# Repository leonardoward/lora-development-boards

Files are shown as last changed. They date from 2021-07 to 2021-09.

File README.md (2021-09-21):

# RFM95W-915S2 Development Board #

<p align="center">
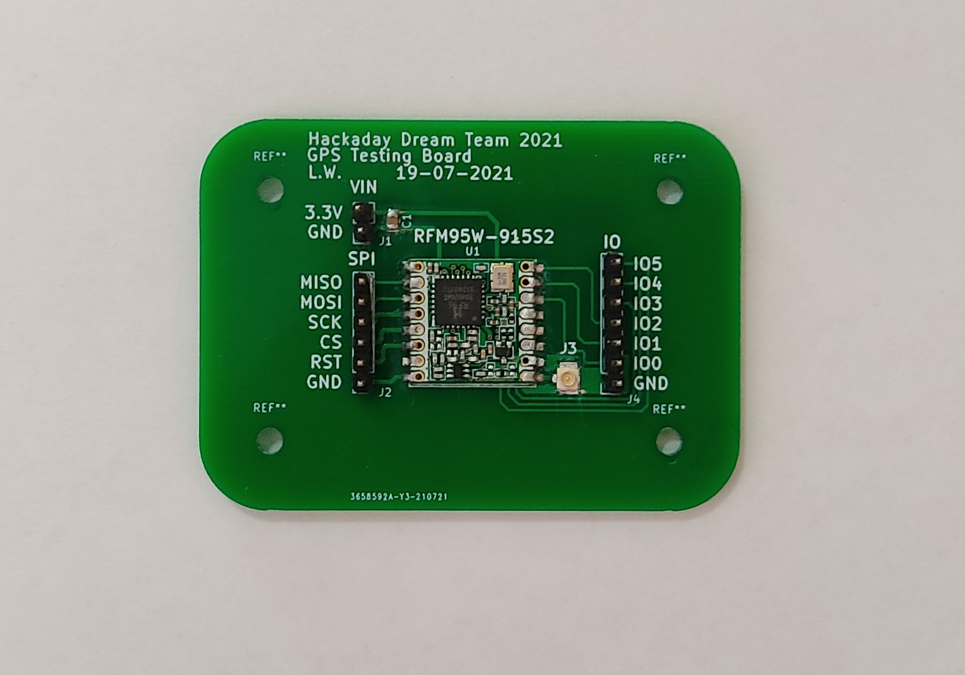
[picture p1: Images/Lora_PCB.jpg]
  
</p>

This repository contains the design of a development board for the RFM95W-915S2. The PCB was designed using KiCad.

The [RFM95W-915S2 Development board](https://hackaday.io/project/173457/log/196116-lora-rfm95w-915s2-development-board) is a PCB that contains a RFM95W LoRa transceiver, a [U.FL connector](https://www.digikey.com/en/products/detail/hirose-electric-co-ltd/U-FL-R-SMT-1-10/2391570) for the external antenna, a decoupling capacitor and a group of headers connected to the different pins of the transceiver. The transceiver can be used as a sender or a receiver.

## Table of Contents

1. [Schematic](#schematic)
2. [Bill of Materials](#bill-of-materials)
3. [3D Model](#3d-model)
4. [Firmware and Testing](#firmware-and-testing)
5. [Authors](#authors)

## Schematic ##

<p align="center">
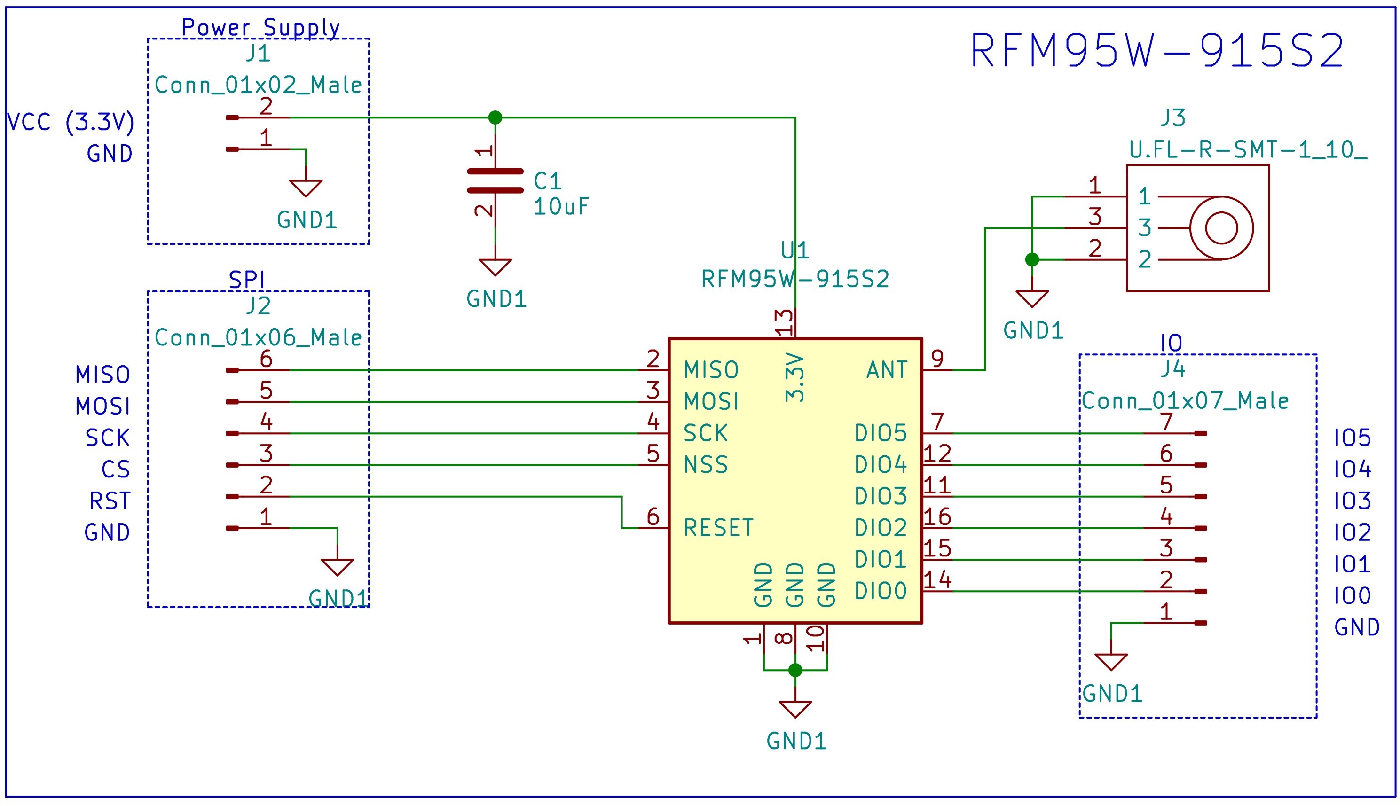
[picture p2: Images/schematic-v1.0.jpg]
  
</p>

**[Back to top](#table-of-contents)**

## Bill of Materials ##

| Reference | Quantity |
| --- | --- |
| [RFM95W-915S2 LoRa™ Transceiver Module 915MHz SMD](https://www.digikey.com/en/products/detail/rf-solutions/RFM95W-915S2/6564923)  | 1 |
| [10 µF ±10% 6.3V Ceramic Capacitor 0805](https://www.digikey.com/en/products/detail/samsung-electro-mechanics/CL21A106KQCLNNC/3888062)  | 1 |
| [U.FL (UMCC) Connector Receptacle, Male Pin 50 Ohm SMD](https://www.digikey.com/en/products/detail/hirose-electric-co-ltd/U-FL-R-SMT-1-10/2391570) | 1 |
| [Conn Header 40POS 2.54](https://www.digikey.com/en/products/detail/3m/2340-6111TG/1237275) | 1 |

**[Back to top](#table-of-contents)**

## 3D Model ##

<p align="center">
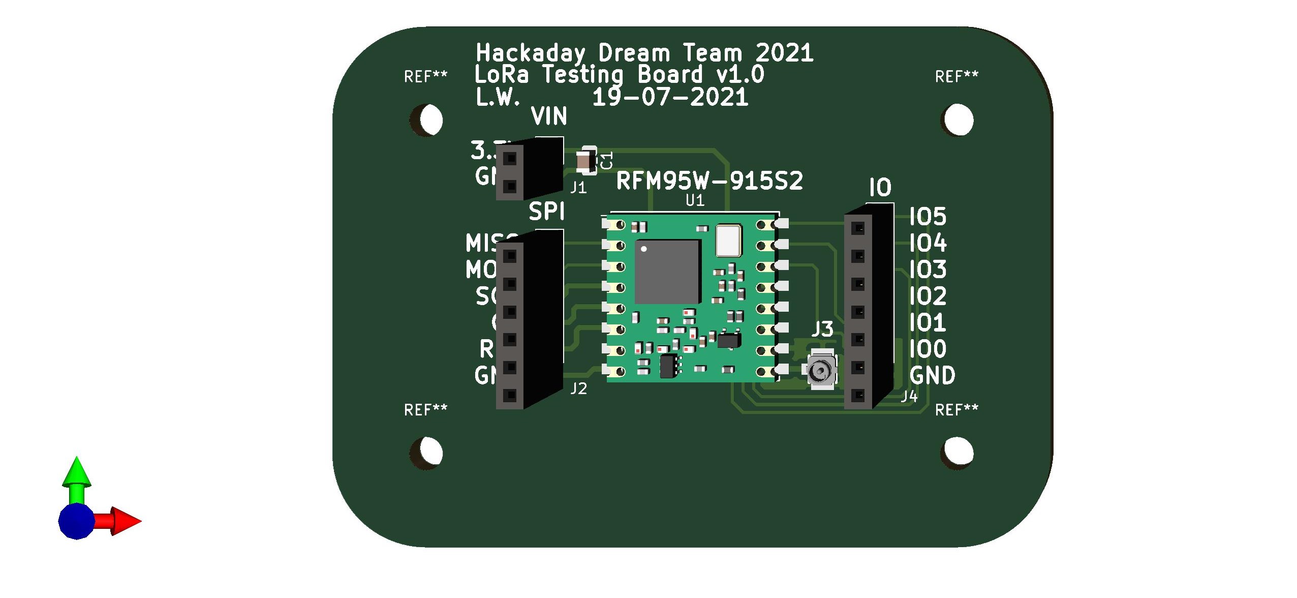
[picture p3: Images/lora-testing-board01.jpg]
  
</p>

<p align="center">
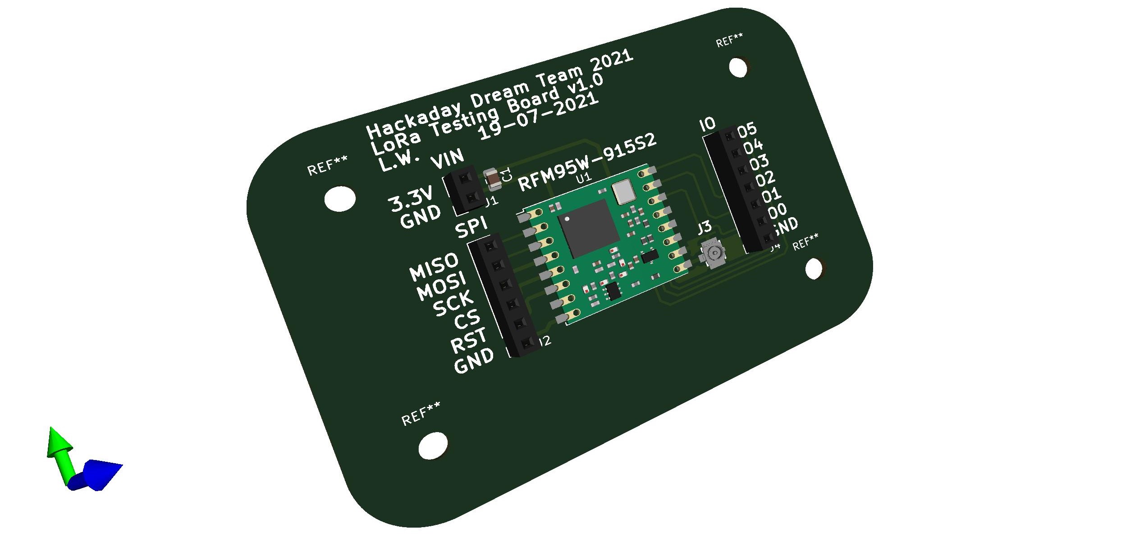
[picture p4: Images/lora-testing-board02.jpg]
  
</p>

**[Back to top](#table-of-contents)**

## Firmware and Testing ##

The webpage randomnerdtutorials.com has an amazing tutorial named [ESP32 with LoRa using Arduino IDE – Getting Started](https://randomnerdtutorials.com/esp32-lora-rfm95-transceiver-arduino-ide/), that tutorial contains detailed information about how to use the RFM95 with an ESP32 (the same microcontroller that was selected for our designs). I used the same firmware and connections provided by the tutorial.

The test requires 2 transceivers, one of them will be used as a sender and the other as a receiver. In this case, one of the transceivers is the  RFM95W-915S2 Development board and the other one is the [RFM95W transceiver from Adafruit](https://www.digikey.com/en/products/detail/adafruit-industries-llc/3072/6005357).

The connections are the following:

| ESP32 | RFM95W-915S2 Development Board |
| --- | --- |
| 3V3  | 3.3V |
| GND  | GND |
| GPIO 14  | RST |
| GPIO 5  | CS |
| GPIO 18  | SCK |
| GPIO 23  | MOSI |
| GPIO 19  | 	MISO |

<p align="center">
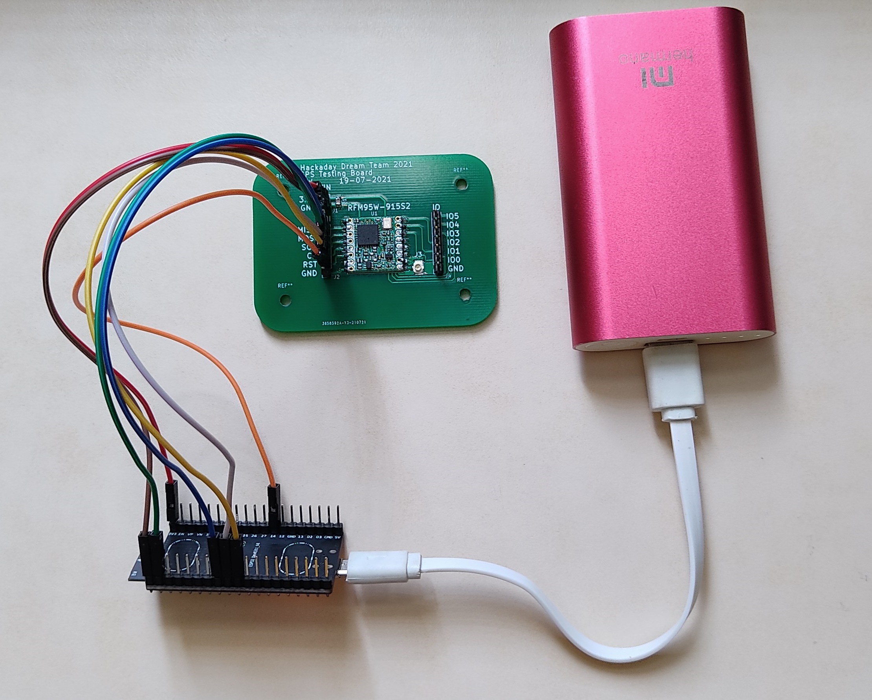
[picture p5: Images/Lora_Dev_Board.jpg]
  
</p>

| ESP32 | RFM95W Board from Adafruit |
| --- | --- |
| 3V3  | VIN |
| GND  | GND |
| GPIO 14  | RST |
| GPIO 5  | CS |
| GPIO 18  | SCK |
| GPIO 23  | MOSI |
| GPIO 19  | 	MISO |

<p align="center">
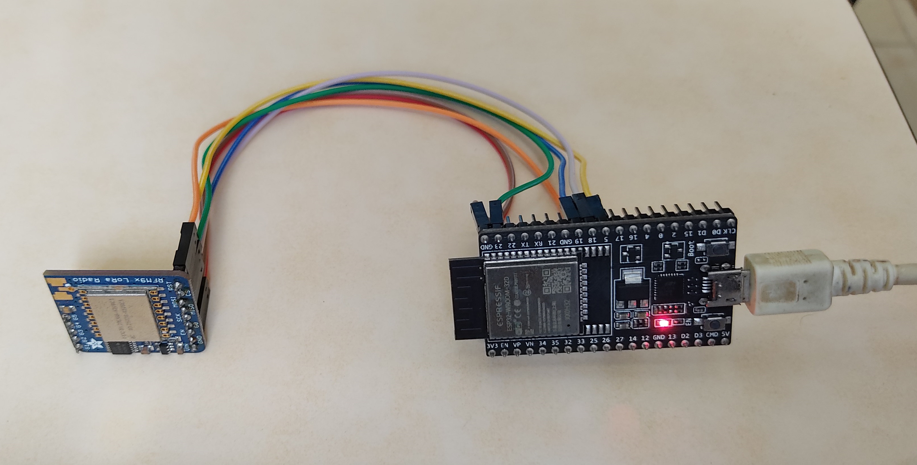
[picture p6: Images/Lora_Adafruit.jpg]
  
</p>

This repository contains a folder named /Firmware/ that contains the project for the transceiver as a [receiver](https://github.com/leonardoward/lora-development-boards/blob/main/Firmware/esp32_RFM95_receiver/esp32_RFM95_receiver.ino) and a [sender](https://github.com/leonardoward/lora-development-boards/blob/main/Firmware/esp32_RFM95_sender/esp32_RFM95_sender.ino).  

Both of the RFM95W Boards were used as a sender and receiver, the result was successful in both cases. During the test, one of the transceivers sends the package "hello counter", where the counter is a number that goes from 0 to 32767. The other transceiver receives the package and prints the message through serial.

### Requisites ###

1. [ESP32 Add-on in Arduino IDE](https://randomnerdtutorials.com/installing-the-esp32-board-in-arduino-ide-windows-instructions/)
2. [LoRa Library](https://randomnerdtutorials.com/esp32-lora-rfm95-transceiver-arduino-ide/)

Results visualized in the serial monitor from the receiver circuit:

<p align="center">
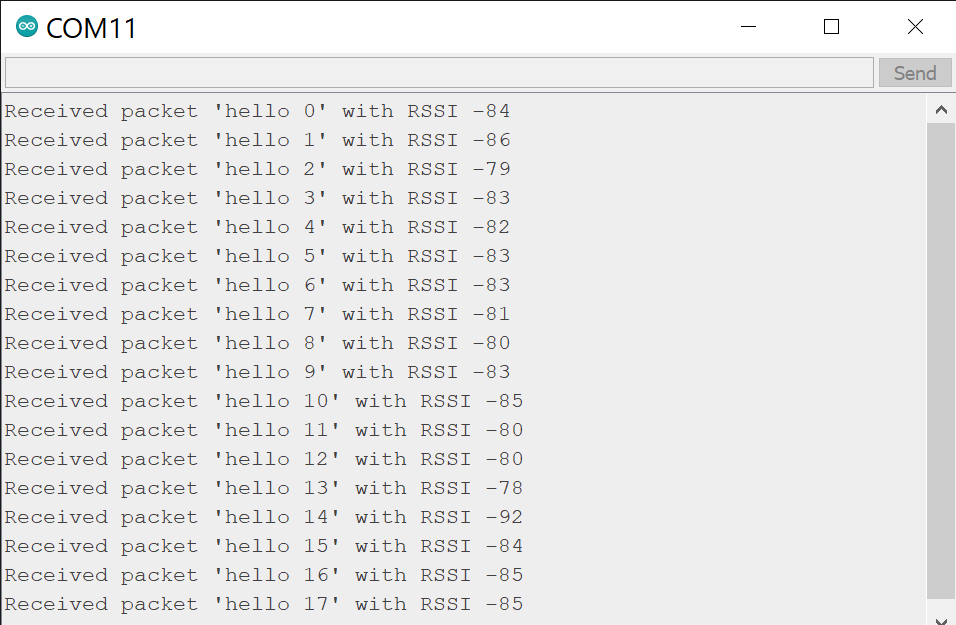
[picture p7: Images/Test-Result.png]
  
</p>

For more information about the firmware visit the [original tutorial for the RFM95W](https://randomnerdtutorials.com/esp32-lora-rfm95-transceiver-arduino-ide/).

**[Back to top](#table-of-contents)**

## Authors ##

* **[Leonardo Ward](https://github.com/leonardoward)**

**[Back to top](#table-of-contents)**

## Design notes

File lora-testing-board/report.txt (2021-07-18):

Info: Checking netlist symbol footprint "C1:/60F514A5:Capacitor_SMD:C_0805_2012Metric".
Info: Checking netlist symbol footprint "J1:/60F44B42:Connector_PinSocket_2.54mm:PinSocket_1x02_P2.54mm_Vertical".
Info: Checking netlist symbol footprint "J2:/60F3E586:Connector_PinSocket_2.54mm:PinSocket_1x06_P2.54mm_Vertical".
Info: Checking netlist symbol footprint "J3:/60F52CF6:U.FL-R-SMT-1(10):U.FL-R-SMT-1_10_".
Info: Checking netlist symbol footprint "J4:/60F51643:Connector_PinSocket_2.54mm:PinSocket_1x07_P2.54mm_Vertical".
Info: Checking netlist symbol footprint "U1:/60F3A12A:RF_Module:HOPERF_RFM9XW_SMD".
Adding new symbol C1 footprint Capacitor_SMD:C_0805_2012Metric.
Adding new symbol J1 footprint Connector_PinSocket_2.54mm:PinSocket_1x02_P2.54mm_Vertical.
Adding new symbol J2 footprint Connector_PinSocket_2.54mm:PinSocket_1x06_P2.54mm_Vertical.
Adding new symbol J3 footprint U.FL-R-SMT-1(10):U.FL-R-SMT-1_10_.
Adding new symbol J4 footprint Connector_PinSocket_2.54mm:PinSocket_1x07_P2.54mm_Vertical.
Adding new symbol U1 footprint RF_Module:HOPERF_RFM9XW_SMD.

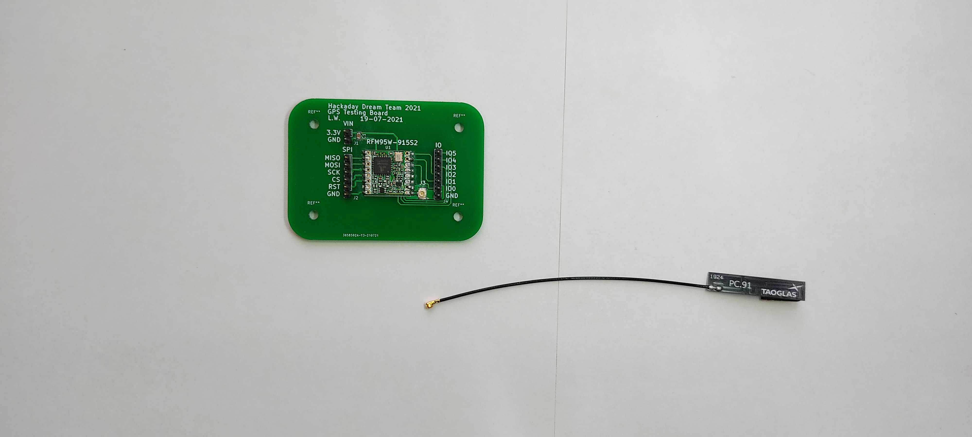
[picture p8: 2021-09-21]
Images/Lora_antena01.jpg

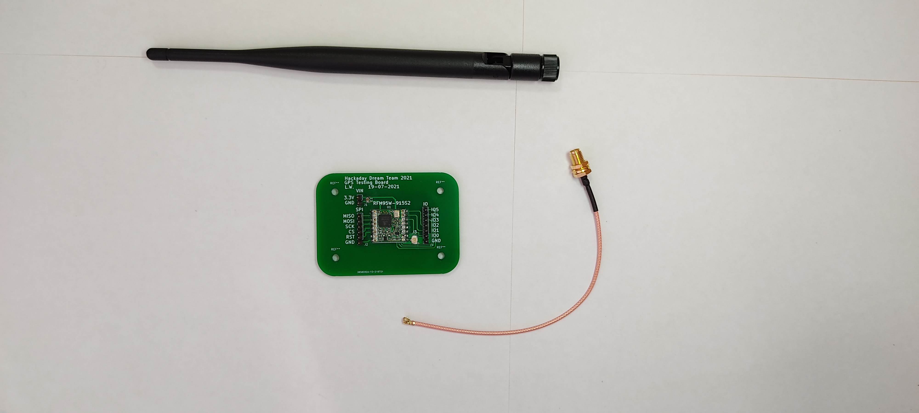
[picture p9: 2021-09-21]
Images/Lora_antena02.jpg

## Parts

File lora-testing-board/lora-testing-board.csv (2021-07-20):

Source: | C:\Ext\lora-development-boards\lora-testing-board\lora-testing-board.sch
Date: | 7/19/2021 5:52:30 PM
Tool: | Eeschema (5.1.10)-1
Generator: | C:\Program Files\KiCad\bin\scripting\plugins/bom_csv_grouped_by_value.py
Component Count: | 6
Individual Components:
Item | Qty | Reference(s) | Value | LibPart | Footprint | Datasheet | Description | Manufacturer | Manufacturer Name | Manufacturer Part Number | Supplier 1 | Supplier 2 | Supplier Part Number 1 | Supplier Part Number 2
 |  | C1 | C-10uF-0805 | C-10uF-0805:C-10uF-0805 | Capacitor_SMD:C_0805_2012Metric |  |  | Samsung Electro-Mechanics |  | CL21A106KQCLNNC | Digi-Key |  | 1276-2404-1-ND
 |  | J1 | Conn_01x02_Male | Connector:Conn_01x02_Male | Connector_PinSocket_2.54mm:PinSocket_1x02_P2.54mm_Vertical | ~
 |  | J2 | Conn_01x06_Male | Connector:Conn_01x06_Male | Connector_PinSocket_2.54mm:PinSocket_1x06_P2.54mm_Vertical | ~
 |  | J3 | U.FL-R-SMT-1_10_ | U.FL-R-SMT-1_10_:U.FL-R-SMT-1_10_ | U.FL-R-SMT-1(10):U.FL-R-SMT-1_10_ | https://www.hirose.com/product/document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 | UFL SMT PCB receptable,DC-6GHz Hirose Straight 50 Surface Mount UFL Connector, Receptacle, Solder Termination Coaxial |  | Hirose | U.FL-R-SMT-1(10) | Digi-Key | Mouser | H11891CT-ND | 798-U.FL-R-SMT-110
 |  | J4 | Conn_01x07_Male | Connector:Conn_01x07_Male | Connector_PinSocket_2.54mm:PinSocket_1x07_P2.54mm_Vertical | ~
 |  | U1 | RFM95W-915S2 | RFM95W-915S2:RFM95W-915S2 | RF_Module:HOPERF_RFM9XW_SMD | https://www.rfsolutions.co.uk/downloads/1463993415RFM95_96_97_98W.pdf |  |  |  |  | Digi-Key |  | RFM95W-915S2-ND
Collated Components:
Item | Qty | Reference(s) | Value | LibPart | Footprint | Datasheet | Description | Manufacturer | Manufacturer Name | Manufacturer Part Number | Supplier 1 | Supplier 2 | Supplier Part Number 1 | Supplier Part Number 2
1 | 1 | C1 | C-10uF-0805 | C-10uF-0805:C-10uF-0805 | Capacitor_SMD:C_0805_2012Metric |  |  | Samsung Electro-Mechanics |  | CL21A106KQCLNNC | Digi-Key |  | 1276-2404-1-ND
2 | 1 | J1 | Conn_01x02_Male | Connector:Conn_01x02_Male | Connector_PinSocket_2.54mm:PinSocket_1x02_P2.54mm_Vertical | ~
3 | 1 | J2 | Conn_01x06_Male | Connector:Conn_01x06_Male | Connector_PinSocket_2.54mm:PinSocket_1x06_P2.54mm_Vertical | ~
4 | 1 | J3 | U.FL-R-SMT-1_10_ | U.FL-R-SMT-1_10_:U.FL-R-SMT-1_10_ | U.FL-R-SMT-1(10):U.FL-R-SMT-1_10_ | https://www.hirose.com/product/document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 | UFL SMT PCB receptable,DC-6GHz Hirose Straight 50 Surface Mount UFL Connector, Receptacle, Solder Termination Coaxial |  | Hirose | U.FL-R-SMT-1(10) | Digi-Key | Mouser | H11891CT-ND | 798-U.FL-R-SMT-110
5 | 1 | J4 | Conn_01x07_Male | Connector:Conn_01x07_Male | Connector_PinSocket_2.54mm:PinSocket_1x07_P2.54mm_Vertical | ~
6 | 1 | U1 | RFM95W-915S2 | RFM95W-915S2:RFM95W-915S2 | RF_Module:HOPERF_RFM9XW_SMD | https://www.rfsolutions.co.uk/downloads/1463993415RFM95_96_97_98W.pdf |  |  |  |  | Digi-Key |  | RFM95W-915S2-ND

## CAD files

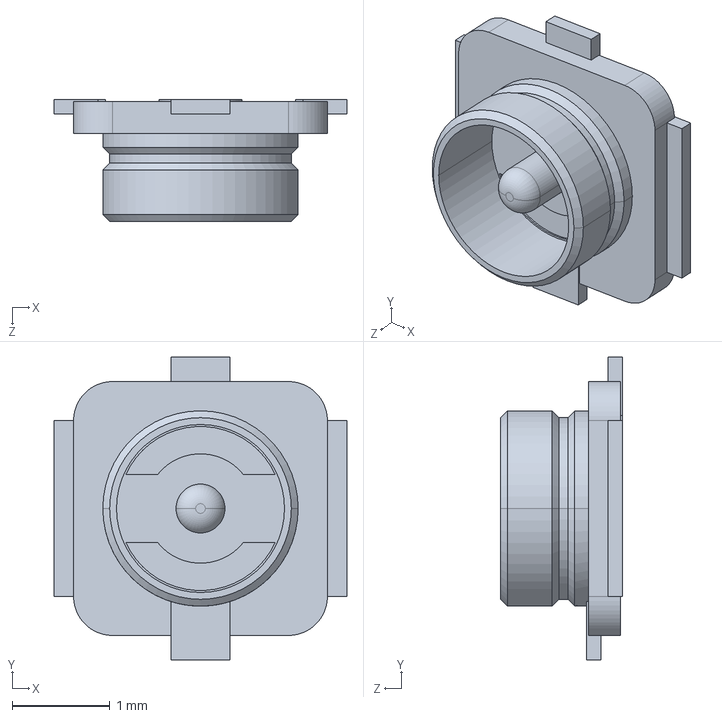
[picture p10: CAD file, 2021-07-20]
lora-testing-board/3D/U.FL-R-SMT-1_10_.stp
3.00 x 3.10 x 1.25 mm

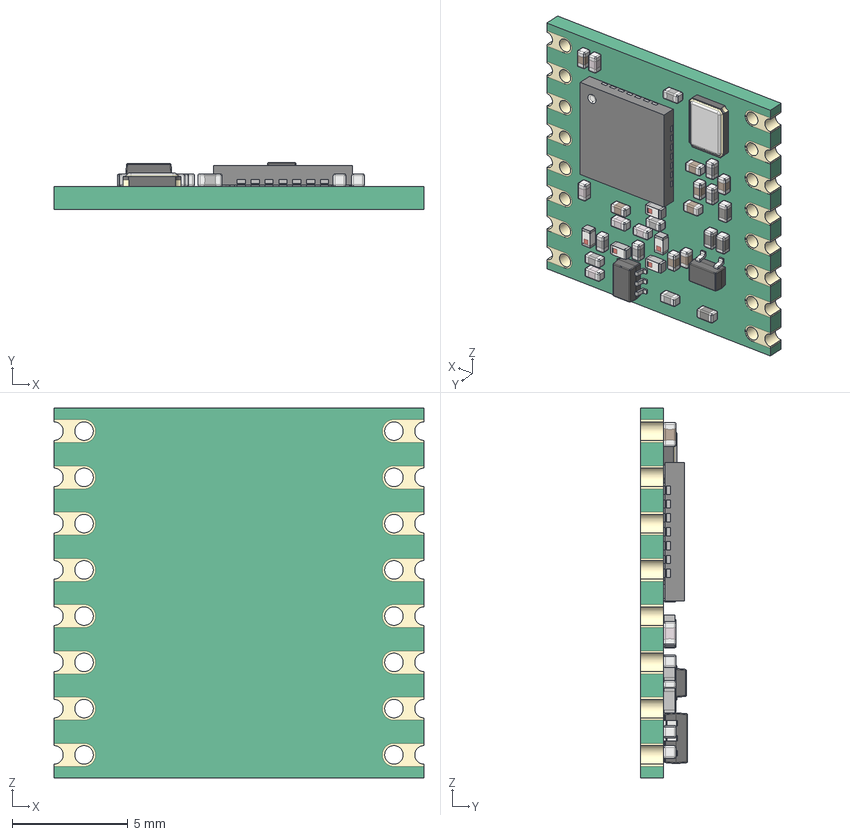
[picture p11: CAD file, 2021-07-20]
lora-testing-board/3D/RFM95 LoRa v15.step
16.0 x 2.04 x 16.0 mm
QFN 28
SMD Crystal
CAP 0403 x 8
CAP Ceramic 0403 x 8
Res 0403 x 4
CAP ML 0403 x 5
SOT-323
Inductor SMD 0403 x 5
SOT-363

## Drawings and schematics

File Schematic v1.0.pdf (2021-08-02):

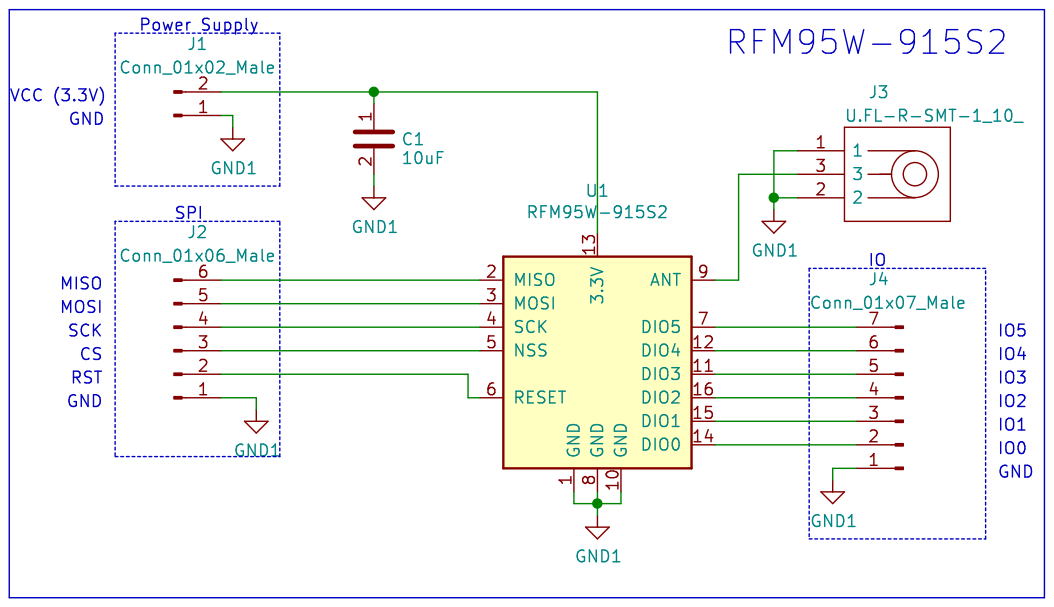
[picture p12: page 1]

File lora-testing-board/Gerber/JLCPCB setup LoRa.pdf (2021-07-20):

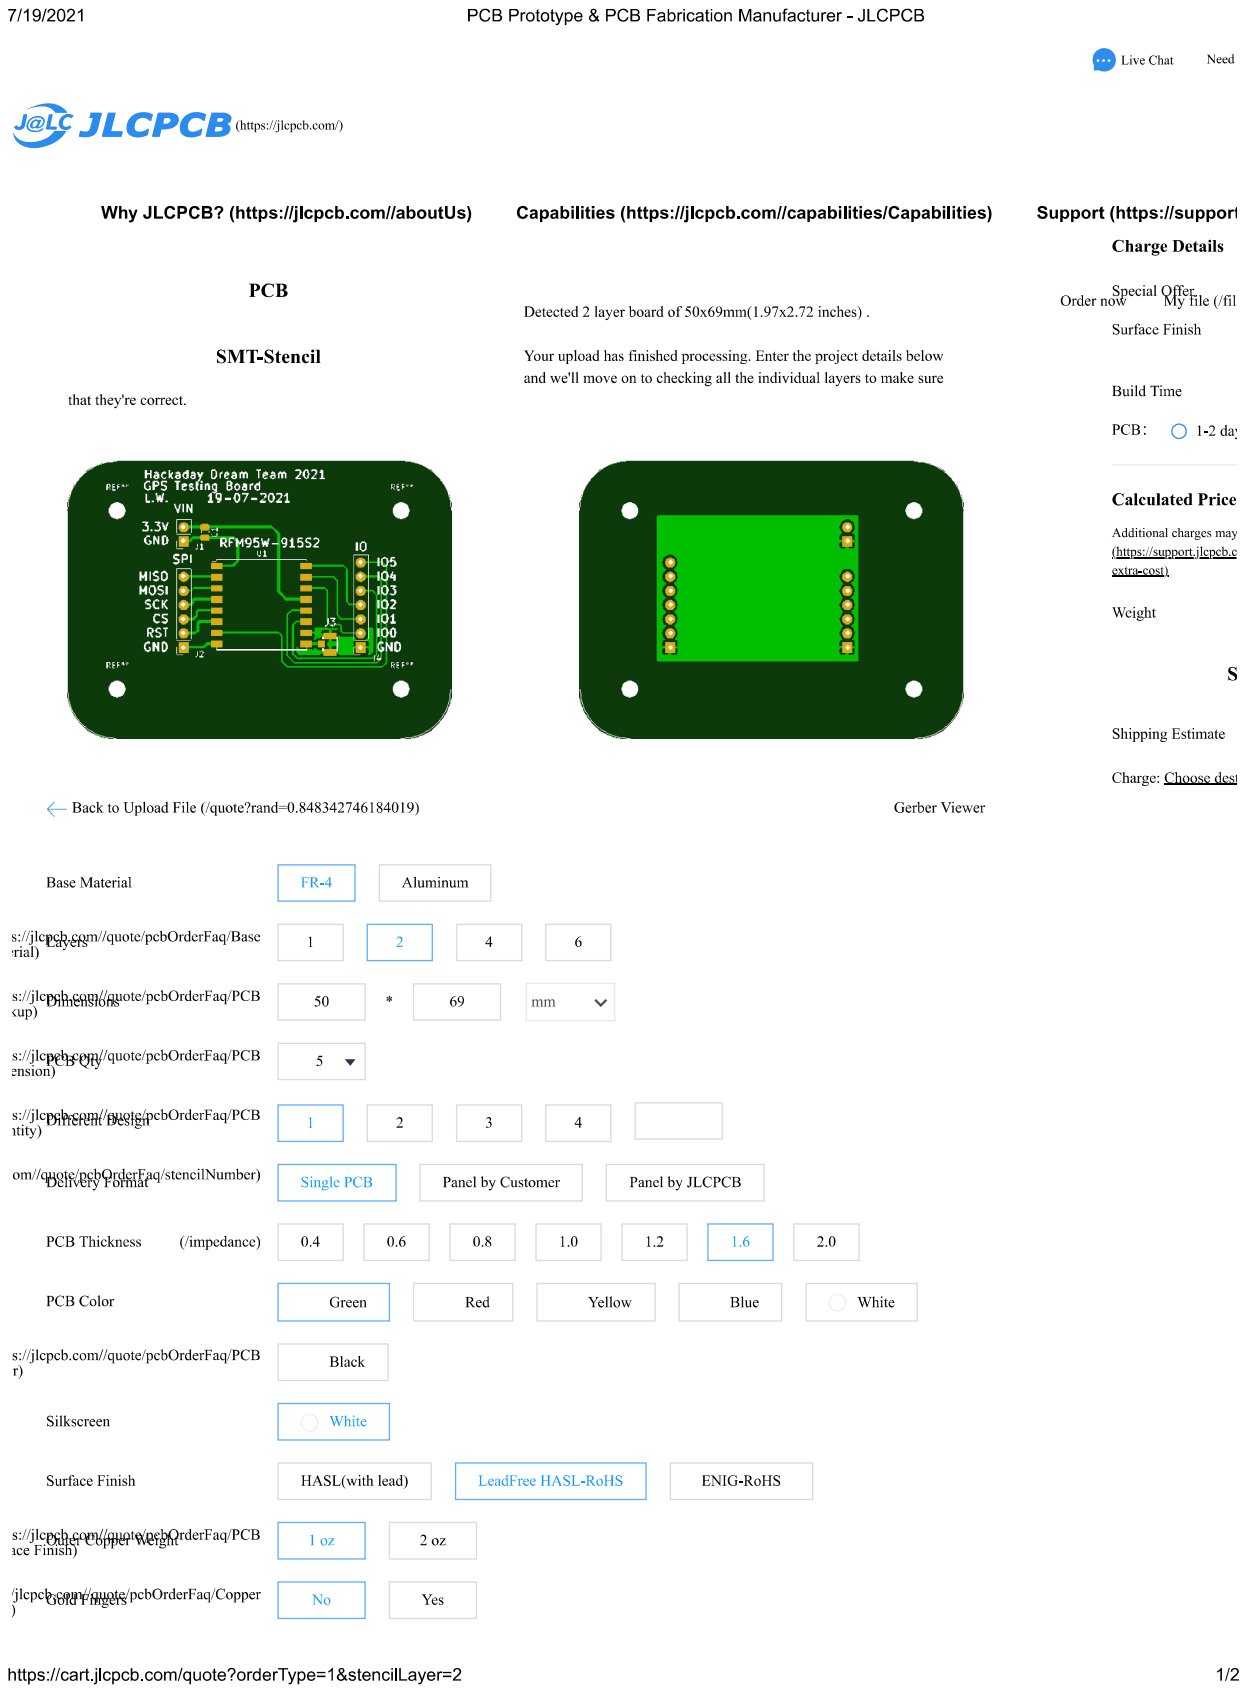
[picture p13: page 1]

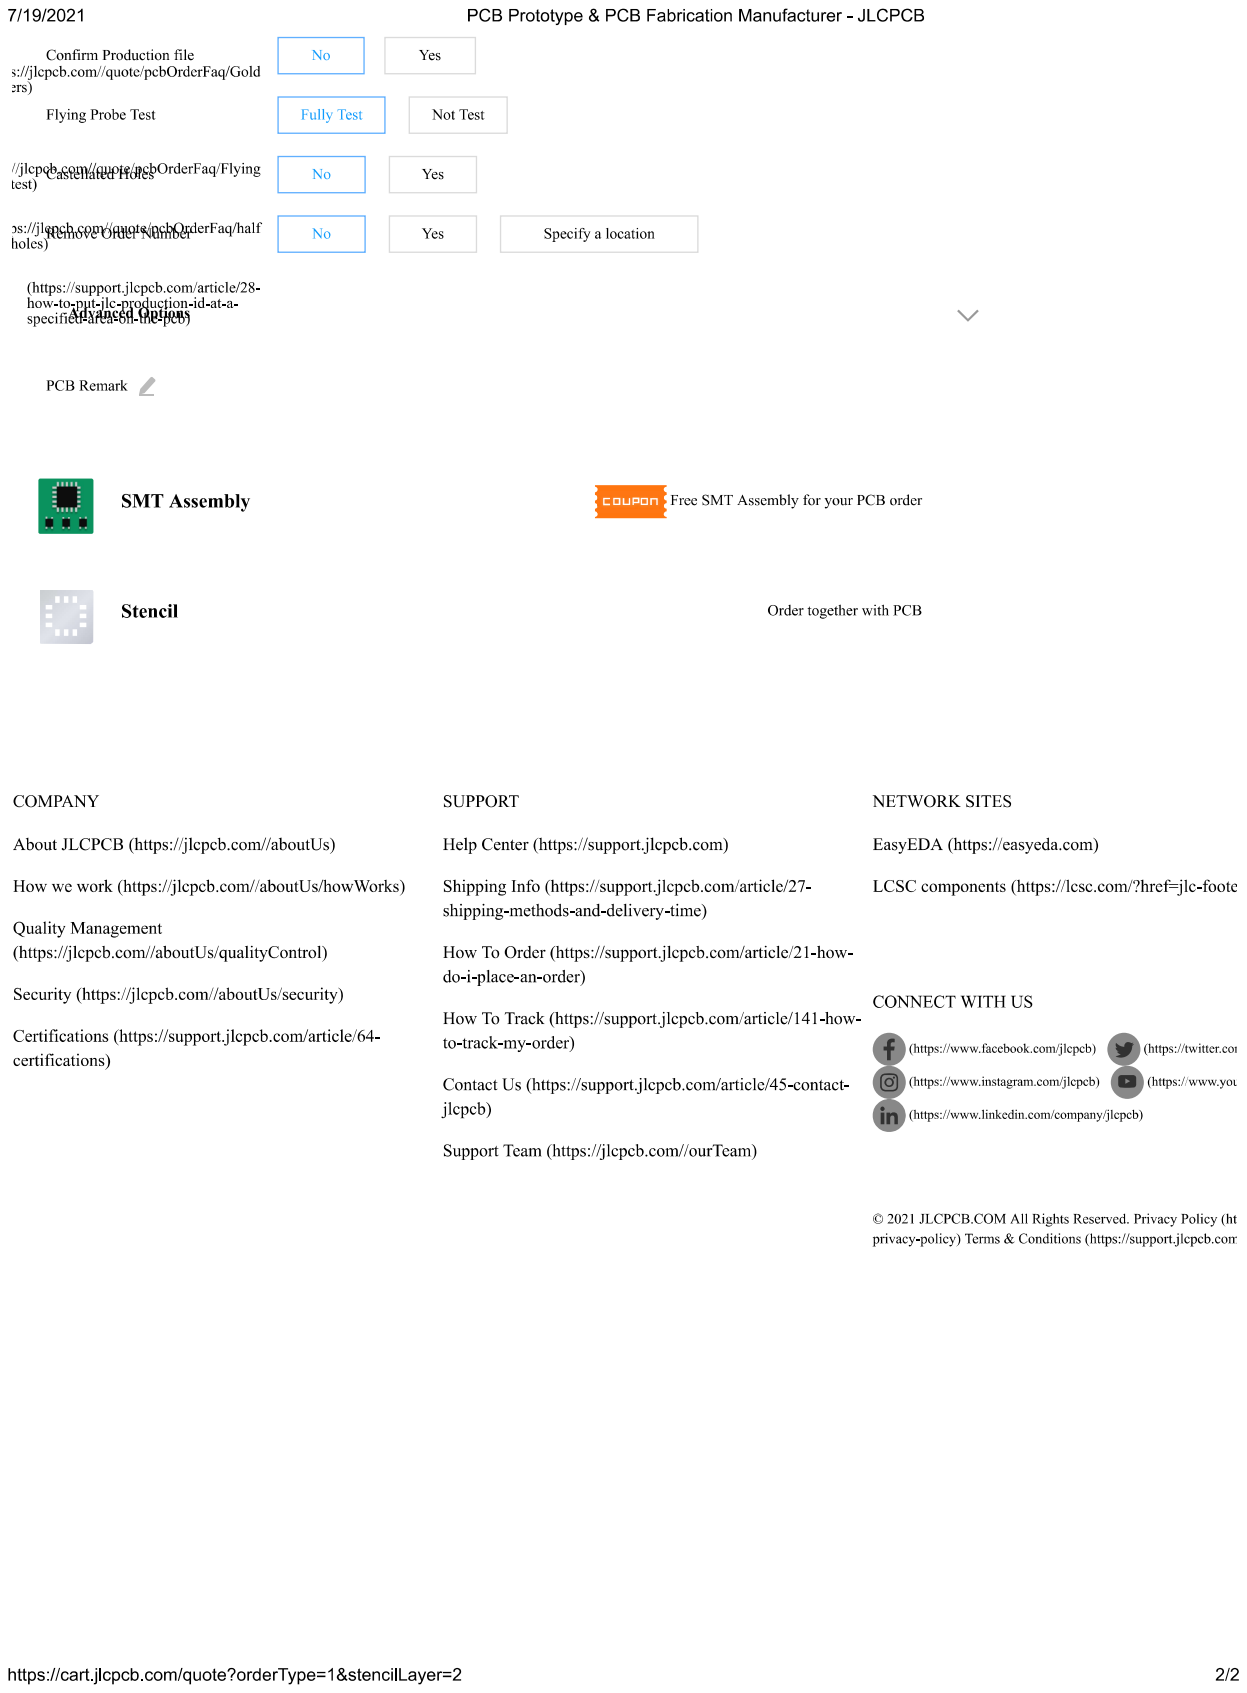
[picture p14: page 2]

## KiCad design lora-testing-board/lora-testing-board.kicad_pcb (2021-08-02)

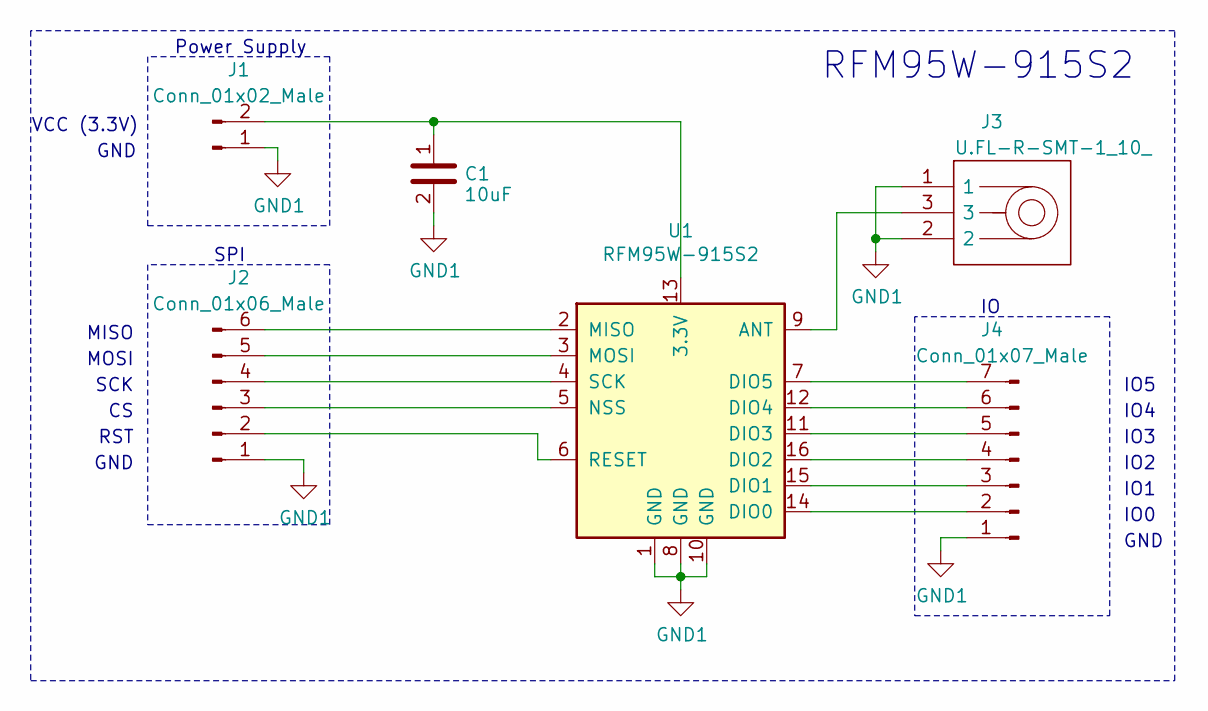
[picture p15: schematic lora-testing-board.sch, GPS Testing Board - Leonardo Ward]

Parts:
C1: 10uF; C_0805_2012Metric; Manufacturer Part Number CL21A106KQCLNNC
J1: Conn_01x02_Male; PinSocket_1x02_P2.54mm_Vertical
J2: Conn_01x06_Male; PinSocket_1x06_P2.54mm_Vertical
J3: U.FL-R-SMT-1_10_; Manufacturer Part Number U.FL-R-SMT-1(10)
J4: Conn_01x07_Male; PinSocket_1x07_P2.54mm_Vertical
U1: RFM95W-915S2; HOPERF_RFM9XW_SMD

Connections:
GND1: C1.2, J1.1, J2.1, J3.1, J3.2, J4.1, U1.1 (GND), U1.8 (GND), U1.10 (GND)
unnamed: C1.1, J1.2, U1.13 (3.3V)
unnamed: J2.2, U1.6 (RESET)
unnamed: J2.3, U1.5 (NSS)
unnamed: J2.4, U1.4 (SCK)
unnamed: J2.5, U1.3 (MOSI)
unnamed: J2.6, U1.2 (MISO)
unnamed: J3.3, U1.9 (ANT)
unnamed: J4.2, U1.14 (DIO0)
unnamed: J4.3, U1.15 (DIO1)
unnamed: J4.4, U1.16 (DIO2)
unnamed: J4.5, U1.11 (DIO3)
unnamed: J4.6, U1.12 (DIO4)
unnamed: J4.7, U1.7 (DIO5)

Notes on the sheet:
Power Supply
SPI
VCC (3.3V)
GND
SCK
MOSI
MISO
RST
IO5
IO4
IO3
IO2
IO1
IO0
RFM95W-915S2

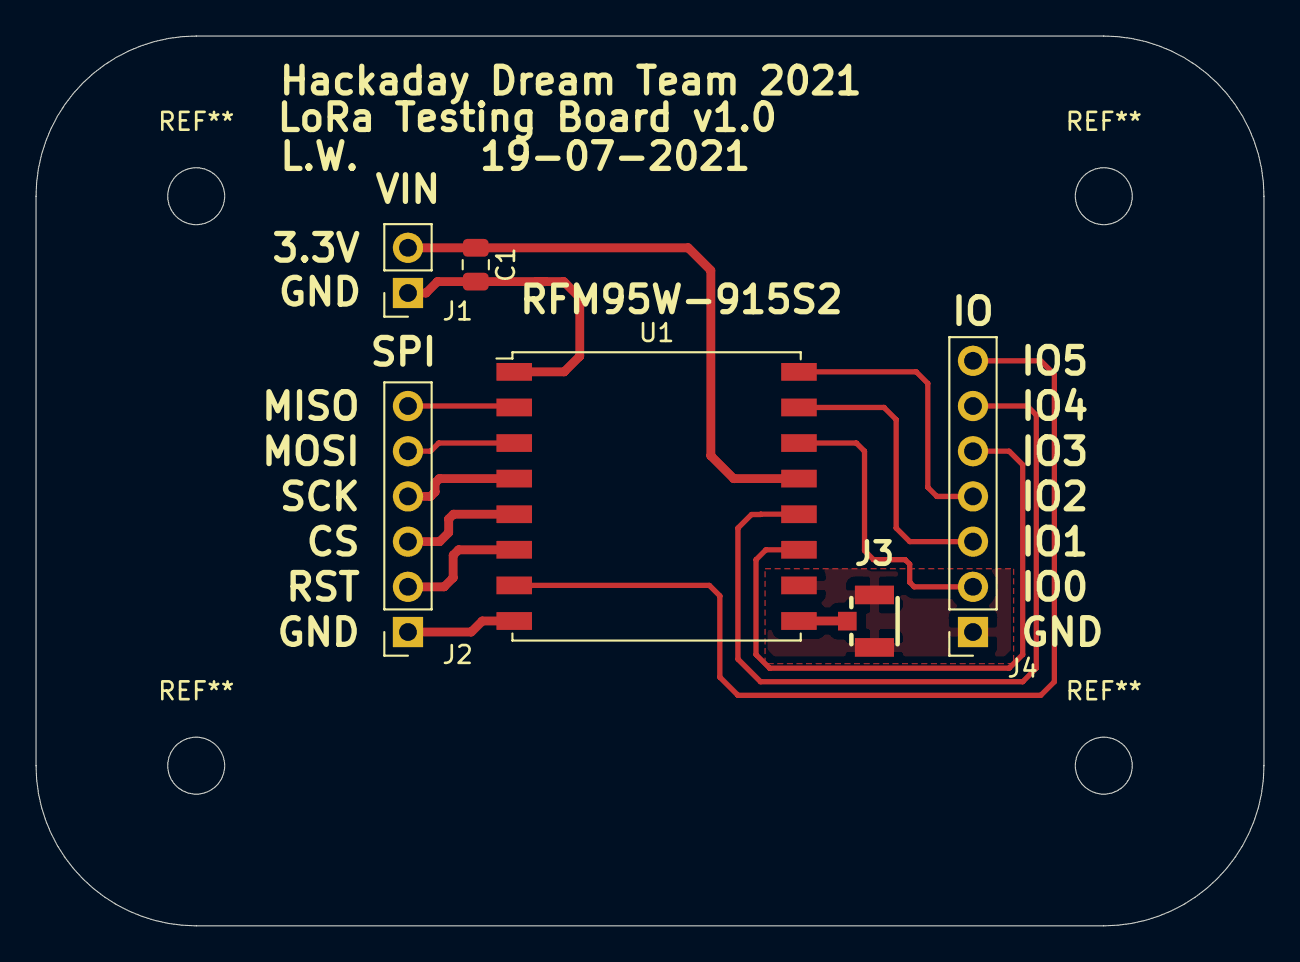
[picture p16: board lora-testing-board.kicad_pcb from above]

Board: 2 copper layers, 69.0 x 50.0 mm, 6 parts (0 on the bottom side), 14 nets.

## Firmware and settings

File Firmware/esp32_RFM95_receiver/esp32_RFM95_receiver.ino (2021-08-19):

/*********
  Modified from the examples of the Arduino LoRa library
  More resources: https://randomnerdtutorials.com
*********/

#include <SPI.h>
#include <LoRa.h>

//define the pins used by the transceiver module
#define ss 5
#define rst 14
#define dio0 2

void setup() {
  //initialize Serial Monitor
  Serial.begin(115200);
  Serial.println("Init");
  while (!Serial){
    Serial.println("Can't find the LoRa Module.");
    delay(200);
  };
  Serial.println("LoRa Receiver");

  //setup LoRa transceiver module
  LoRa.setPins(ss, rst, dio0);
  
  //replace the LoRa.begin(---E-) argument with your location's frequency 
  //433E6 for Asia
  //866E6 for Europe
  //915E6 for North America
  while (!LoRa.begin(866E6)) {
    Serial.println(".");
    delay(500);
  }
   // Change sync word (0xF3) to match the receiver
  // The sync word assures you don't get LoRa messages from other LoRa transceivers
  // ranges from 0-0xFF
  LoRa.setSyncWord(0xF3);
  Serial.println("LoRa Initializing OK!");
}

void loop() {
  // try to parse packet
  int packetSize = LoRa.parsePacket();
  if (packetSize) {
    // received a packet
    Serial.print("Received packet '");

    // read packet
    while (LoRa.available()) {
      String LoRaData = LoRa.readString();
      Serial.print(LoRaData); 
    }

    // print RSSI of packet
    Serial.print("' with RSSI ");
    Serial.println(LoRa.packetRssi());
  }
}

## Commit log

2021-07-14 Added libraries
    [lora-testing-board.kicad_pcb, lora-testing-board.sch]
2021-07-18 Added schematic for RFM95W
    [lora-testing-board.sch]
2021-07-18 Added PCB for RFM95W-915S2
    [lora-testing-board.csv, lora-testing-board.sch]
2021-07-20 Added IDFv3 and Gerber
    [RFM95 LoRa v15.step, U.FL-R-SMT-1_10_.stp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]
2021-08-02 Updated schematic, gerbers and added README
    [lora-testing-board-B_Cu.gbr, lora-testing-board-B_Mask.gbr, lora-testing-board-B_Paste.gbr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]
